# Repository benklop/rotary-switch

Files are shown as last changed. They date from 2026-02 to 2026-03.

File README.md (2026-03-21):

# Rotary Light Switch

3D-printed single-gang US rotary light switch using an EC11 encoder and ESP32-S2 Mini, with a standard faceplate and knob. Control a dimmable/color light from Home Assistant: toggle, dim, hue, and color temperature. Optional RGB LED behind the knob for feedback or night light (controllable as a light in HA).

## Contents

- **openscad/** – Housing (single-gang, 2 3/8" faceplate screws, 3 9/32" box mount). No printed faceplate; use a standard toggle/rotary-dimmer plate.
- **esphome/** – ESPHome config for Lolin S2 Mini: rotary encoder + push button, exposed to Home Assistant.
- **homeassistant/blueprints/automation/** – Speed-sensitive RGB blueprints (`rotary_dimmer_rgb.yaml`, `rotary_dimmer_rgb_with_fan.yaml`): Encoder Speed sensor, Kelvin CT on the light, saturation-first hue mode. With the optional fan button configured, double-press is hue and the fan button toggles fan; without it, double-press toggles fan mode. See [homeassistant/blueprints/automation/README.md](homeassistant/blueprints/automation/README.md).
- **docs/** – Wiring, BOM, assembly.

## Quick start

1. Print the housing (`openscad/`), flash ESPHome (`esphome/`), wire encoder and PSU (see [docs/wiring.md](docs/wiring.md)).
2. Mount encoder, boards, and knob in the housing; install in the wall with a standard faceplate.
3. In Home Assistant, add the device, create the helpers for your blueprint (mode input_select, hue sub-mode select for RGB blueprints, optional fan button entity, 30 s timer — see [homeassistant/blueprints/automation/README.md](homeassistant/blueprints/automation/README.md)), then create an automation from `rotary_dimmer_rgb.yaml` or `rotary_dimmer_rgb_with_fan.yaml`.

See [docs/assembly.md](docs/assembly.md) and [docs/bom.md](docs/bom.md) for full steps and parts.

## Hardware

- EC11 rotary encoder (15 mm shaft, **splined** 6 mm)
- ESP32-S2 Mini (Lolin S2 Mini), [pinout](https://done.land/components/microcontroller/families/esp/esp32/developmentboards/esp32-s2/s2mini/)
- WX-DC12003 5 V 700 mA PSU (23.5×18.1 mm)
- Lutron knob (5.5 mm split-shaft type; heat and form to fit 6 mm splined encoder—see docs); standard single-gang faceplate

## License

Use and modify as you like; no warranty.

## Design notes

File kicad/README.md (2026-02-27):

## KiCad: Rotary switch UI PCB

This folder contains a small PCB intended to mount:

- An **EC11/EC11E-style rotary encoder with push switch**
- A **5 mm through-hole common-cathode RGB LED**
- **3× current-limit resistors** for the LED
- A **1×8 2.54 mm header** for wiring to the ESP32-S2 Mini

### Project files

- `rotary_switch_ui.kicad_pro`
- `rotary_switch_ui.kicad_sch`
- `rotary_switch_ui.kicad_pcb`

### Mechanical reference

The PCB footprint placement is aligned to the OpenSCAD model:

- **Encoder center** at `(0, 0)` mm
- **LED center** at `(0, -9.5)` mm (from `openscad/dimensions.scad` `led_offset_y`)

### Recommended footprints (to assign in schematic)

If you open the schematic and run **Update PCB from Schematic**, assign these footprints first so KiCad can match by reference designator:

- `SW1` (encoder): `Rotary_Encoder:RotaryEncoder_Alps_EC11E-Switch_Vertical_H20mm`
- `D1` (LED): `LED_THT:LED_D5.0mm-4_RGB`
- `R1`, `R2`, `R3` (resistors): `Resistor_SMD:R_0805_2012Metric` (or switch to THT if preferred)
- `J1` (to ESP32): `Connector_PinHeader_2.54mm:PinHeader_1x08_P2.54mm_Vertical`

### Header pinout (J1)

1. `+3V3` (optional; typically not needed for a bare EC11)
2. `GND`
3. `ENC_A` (encoder A → ESP32 GPIO34 per `docs/wiring.md`)
4. `ENC_B` (encoder B → ESP32 GPIO36)
5. `ENC_BTN` (push button → ESP32 GPIO37)
6. `LED_R_IN` (→ R1 → LED_R; ESP32 GPIO4)
7. `LED_G_IN` (→ R2 → LED_G; ESP32 GPIO5)
8. `LED_B_IN` (→ R3 → LED_B; ESP32 GPIO6)

# Rotary front panel PCB

Small PCB to mount the EC11 encoder, 5 mm RGB LED, and current-limiting resistors for the [rotary light switch](../README.md) project. Connects to the ESP32-S2 Mini via a 8-pin header.

## Contents

- **rotary-front.kicad_pro** – KiCad 8 project
- **rotary-front.kicad_pcb** – Board with footprints placed (encoder, LED, 3× 0805 resistors, 1×8 pin header). No schematic yet; create one and then **Update PCB from Schematic**.

## Schematic (create in Eeschema)

Create a new schematic in this project and add:

| Ref | Symbol / part | Footprint | Value / notes |
|-----|---|---|---|
| U1 | **Device:RotaryEncoder_Switch** | **Rotary_Encoder:RotaryEncoder_Alps_EC11E-Switch_Vertical_H20mm** | EC11 with switch |
| D1 | **LED:LED_RGB_CommonCathode** or 4-pin connector | **LED_THT:LED_D5.0mm-4_RGB** | 5 mm common-cathode RGB |
| R1 | **Device:R** | **Resistor_SMD:R_0805_2012Metric** | **470 Ω** (red channel) |
| R2 | **Device:R** | **Resistor_SMD:R_0805_2012Metric** | **430 Ω** (green) |
| R3 | **Device:R** | **Resistor_SMD:R_0805_2012Metric** | **430 Ω** (blue) |
| J1 | **Connector:Conn_01x08** | **Connector_PinHeader_2.54mm:PinHeader_1x08_P2.54mm_Vertical** | To ESP32 |

### Net list (wire to J1)

Use these net names so the PCB matches [../docs/wiring.md](../docs/wiring.md):

| J1 pin | Net name | ESP32-S2 Mini |
|---|---|---|
| 1 | +3V3 (opt) | 3V3 |
| 2 | GND | GND |
| 3 | ENC_A | GPIO 34 |
| 4 | ENC_B | GPIO 36 |
| 5 | ENC_BTN | GPIO 37 |
| 6 | LED_R_IN | GPIO 4 (via R1 470 Ω) |
| 7 | LED_G_IN | GPIO 5 (via R2 430 Ω) |
| 8 | LED_B_IN | GPIO 6 (via R3 430 Ω) |

- Connect **encoder** pins to ENC_A, ENC_B, ENC_BTN, and GND (check your EC11 datasheet for pin order; Alps EC11E footprint uses A, B, C, S1, S2 — map A/B/S1/S2 to ENC_A/ENC_B/ENC_BTN and GND as appropriate; no VCC is required for the encoder itself).
- Connect **LED** common cathode to **GND**; connect R, G, B anodes to the **R**, **G**, **B** nets (i.e. through R1, R2, R3 to the same-named J1 pins). Verify 5 mm RGB pinout (common cathode vs anode, R/G/B order) from your LED datasheet.

Then: **Tools → Assign footprint symbols**, assign the footprints above, **File → Update PCB from Schematic**, and in PCB Editor route the nets (or use the existing placement).

## PCB layout

- **Board size:** 50 mm × 35 mm (Edge.Cuts).
- **Encoder** at top center (shaft position aligned with front-panel 6 mm hole when the board is mounted).
- **LED** below the encoder (matches `led_offset_y = -9.5 mm` in the OpenSCAD dimensions).
- **J1** at bottom for cable to ESP32.

If your front panel or enclosure differs, move footprints in PCB Editor and adjust Edge.Cuts as needed.

## BOM (per board)

| Ref | Part | Value / spec |
|-----|---|---|
| U1 | Alps EC11 or compatible rotary encoder with switch, vertical, 6 mm shaft | 15 mm shaft, splined |
| D1 | 5 mm RGB LED, common cathode | 4-pin |
| R1 | Resistor 0805 | **470 Ω** |
| R2 | Resistor 0805 | **430 Ω** |
| R3 | Resistor 0805 | **430 Ω** |
| J1 | Pin header 1×8, 2.54 mm | Straight, THT |

## Manufacturing

- Single-sided (or two-layer) 1.6 mm FR4; 0.2 mm min trace/space is fine.
- After assembly, mount the PCB behind the 3D-printed front face with the encoder shaft through the 7 mm hole and the LED in the LED cavity; then follow the main [assembly](../docs/assembly.md) for wiring to the ESP32 and PSU.

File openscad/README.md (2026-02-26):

# Rotary Light Switch – OpenSCAD (front panel + back box)

Two **separate printable components** that attach with 4× M3×10 countersunk screws into M3×6 heat-set inserts in the back box.

## Components

### 1. Front panel (`front_lid.scad`)

Flat plate with hole positions for US single-gang: **narrower and shorter**, ~1/4" beyond the outlet box mounting holes.

- **Faceplate screws** (2 3/8" c/c): 2.6 mm holes so 6-32 screws tap into plastic.
- **Outlet box mounting** (3 9/32" c/c): clearance holes.
- **Encoder**: 6 mm shaft hole; **RGB LED**: 4 mm light opening below.
- **4× M3 countersunk** holes for attaching the back box (M3×10 CS from front into inserts).

### 2. Back box (`back_box.scad`)

Box behind the front panel: **height = distance between faceplate mounting holes** (2 3/8" = 60.325 mm) so it fits in the available space in the light switch box. Minimal depth for encoder rear and boards.

- **4× M3×6 heat-set inserts** at the same positions as the front panel M3 holes (press in from inside).
- **Center divider** separating microcontroller (right / +x) from power supply and 120 V wiring (left / −x).
- **2× wire holes** on the back (PSU side) for 16 AWG live and neutral to the PSU module.

## Dimensions (see `dimensions.scad`)

- Panel: `front_width` (~44 mm), `front_height` (~96 mm), `margin_beyond_box_holes` (1/4").
- Back box: `back_box_height` = faceplate screw spacing (60.325 mm), `back_box_internal_depth` (26 mm), `divider_thickness` (2 mm), `wire_hole_dia` (4 mm).
- M3: `m3_clearance_dia`, `m3_cs_head_dia`, `m3_insert_od`, `m3_insert_depth`, `mount_offset_x` / `mount_offset_y`.

## Usage

1. Open `front_lid.scad` or `back_box.scad` in OpenSCAD (each includes `dimensions.scad`).
2. Adjust values in `dimensions.scad` if needed.
3. Render (F6) and export STL for each component.

## Print settings

- **Front panel**: print with front face down (holes up); no supports. Faceplate holes for 6-32 tap; M3 holes are countersunk.
- **Back box**: orient so the mating face (with the four bosses) is down or so the back wall is down; add supports if the divider or bosses need them. After printing, install M3×6 heat-set inserts in the four boss holes (heat and press in).

## Assembly

1. Install heat-set inserts in the back box (4× M3×6 in the boss holes).
2. Mount encoder (and LED) on the front panel; route wires into the back box.
3. Place ESP32 on the MCU side of the divider, PSU on the PSU side; pass 16 AWG through the two back holes to the PSU.
4. Mate the back box to the front panel and secure with 4× M3×10 countersunk screws from the front.
5. Mount to the outlet box and attach the standard faceplate. See `docs/assembly.md` for full build.

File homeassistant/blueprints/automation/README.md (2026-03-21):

# Rotary Encoder Dimmer Blueprints

Use these blueprints with the ESPHome **rotary-lightswitch** firmware in this repo. Rotation speed comes from the on-device **Encoder Speed** sensor (det/s).

**No Home Assistant helpers are required.** Flash the firmware, import the blueprint, then pick the **light** (and **fan** for the fan blueprint) plus the **rotary ESPHome device**. Mode (`normal` / `hue` / `color_temp` / `fan`), hue sub-mode (`saturation` / `hue`), and the idle timeout are handled on the ESP32 (`select` + `script` + **Mode Idle Arm** / **Mode Idle Cancel** buttons). Idle duration is the `idle_timeout` substitution in [esphome/rotary-lightswitch.yaml](../../esphome/rotary-lightswitch.yaml).

On-device entity suffixes (for debugging): `_encoder_speed`, `_button_single` / `_button_double` / `_button_long`, `_knob_led`, `_rotary_mode`, `_hue_adjust`, `_mode_idle_arm`, `_mode_idle_cancel`.

---

## Blueprint: `rotary_dimmer_rgb.yaml` (speed-sensitive light + hue + color temp)

**Hue mode** starts in **saturation**; **single-press** in hue mode toggles saturation ↔ hue (does not toggle the room light).

**Colour temperature** uses `light.turn_on` **`color_temp_kelvin`** on the main light. The **knob LED** is RGB-only (warm/cool proxy in CT mode).

**Long press**: Firmware fires **Button Long** ~500 ms into the hold so CT mode starts while you are still pressing.

### Setup

1. Flash [esphome/rotary-lightswitch.yaml](../../esphome/rotary-lightswitch.yaml).
2. Import `rotary_dimmer_rgb.yaml`, create the automation: **Light**, **rotary device**, optional “use Knob LED”, optional tuning numbers (defaults are fine).
3. If upgrading from an older blueprint, **re-create** the automation so inputs match.

### Behavior

- **Single / double / long press** and **rotate**: as in the in-blueprint description (normal / hue / CT; double-press hue in/out).

---

## Blueprint: `rotary_dimmer_rgb_with_fan.yaml` (light + fan + hue + CT)

Same RGB / Kelvin / hue behaviour as the RGB-only blueprint, plus **fan** mode on the device’s mode select.

**Double-press vs fan**: Optional **fan button** binary sensor — if set, double-press is for hue and the fan button toggles fan mode; if omitted, double-press toggles fan mode.

### Setup

1. Same firmware as above (mode select includes `fan`).
2. Import `rotary_dimmer_rgb_with_fan.yaml`: **Light**, **fan**, **rotary device**, optional **fan button**, optional knob LED and tuning inputs.
3. Remove any legacy `homeassistant/packages/rotary_dimmer_light.yaml` merge if you still had helpers defined there.

### Behavior

- As described in the blueprint (fan LED colours, CT, hue, etc.).

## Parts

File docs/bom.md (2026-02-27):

# Bill of materials (BOM)

| Item | Spec / link | Qty |
|---|---|-----|
| EC11 rotary encoder with switch | 15 mm shaft, **splined** 6 mm (not D-shaft). Various suppliers (e.g. search “EC11 splined shaft”) | 1 |
| ESP32-S2 Mini | Lolin / Wemos S2 Mini, [e.g. Amazon B0B9ZZYFZ4](https://www.amazon.com/gp/product/B0B9ZZYFZ4). Pinout: [DONE.LAND S2 Mini](https://done.land/components/microcontroller/families/esp/esp32/developmentboards/esp32-s2/s2mini/) | 1 |
| 5 V 700 mA power supply | WX-DC12003, 23.5×18.1 mm, contacts on long side. [Datasheet](https://www.jouyaelec.ir/stfiles/getappdocument/1/true/ac92859d-dfbc-4501-aee5-b14eae599f2f.pdf). [Example Amazon B0B2RBP1Z2](https://www.amazon.com/gp/product/B0B2RBP1Z2) | 1 |
| Lutron knob | Designed for 5.5 mm split shaft; see assembly for fitment (heat and form with encoder shaft) | 1 |
| Standard single-gang faceplate | Toggle / rotary-dimmer style (not printed) | 1 |
| Wire | 22–26 AWG for low voltage between encoder, ESP32, and PSU | ~0.5 m |
| Mounting screws | For outlet box (through 3 9/32" holes) and for faceplate (into 2 3/8" holes); #6-32 or M3 typical | 4 |
| 5 mm RGB LED (common cathode) | Tri-color for feedback / night light behind knob | 1 |
| Resistors | 470 Ω (R), 430 Ω × 2 (G, B), 1/4 W current-limiting | 3 |
| Optional | Heat-set inserts for faceplate screw holes; double-sided tape or small screws for boards in slots | — |

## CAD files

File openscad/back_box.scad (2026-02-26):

// Rotary Light Switch - back box (separate component)
// Attaches to front panel with 4× M3×10 countersunk screws into M3×6 heat-set inserts.
// Divider separates MCU (top) from PSU + 120V (bottom). Two wire holes on back in bottom for live/neutral.

include <dimensions.scad>

// --- Helpers ---
boss_radius = (m3_insert_od + 4) / 2;
r = round_radius;  // fillet radius for rounded edges/corners
rib_width = 2.5;   // rib thickness (perpendicular to wall)
rib_boss_overlap = 0.5;  // rib extends into boss by this much for a solid union

module m3_insert_boss() {
  // Boss recessed by m3_boss_rear_cylinder_height so back box front face is flush for lip; stepped hole for screw + insert
  z_front = back_box_total_depth - m3_boss_rear_cylinder_height;  // front face of boss (recessed)
  boss_h = back_box_total_depth - m3_boss_rear_cylinder_height;
  insert_h = m3_insert_depth * 1.5;
  difference() {
    cylinder(d = m3_insert_od + 4, h = boss_h, $fn = 32);
    // Screw clearance through first 2 mm from boss front face
    translate([0, 0, z_front - 1.5])
      cylinder(d1 = m3_insert_od + 0.1, d2 = m3_insert_od + 1, h = 1.5, $fn = 24);
    // Insert cavity starting 2 mm behind boss front face
    translate([0, 0, z_front - insert_h])
      cylinder(d = m3_insert_od + 0.1, h = insert_h, $fn = 24);
  }
}

// Rib from boss to wall; height matches recessed boss so rib doesn't extend past front face
rib_height = back_box_total_depth - m3_boss_rear_cylinder_height;

module boss_rib_x(boss_x, boss_y, toward_positive) {
  inner_x = toward_positive ? (front_width/2 - wall_thickness) : (-front_width/2 + wall_thickness);
  span = abs(inner_x - boss_x) - boss_radius;          // free gap from boss surface to wall
  len = span + rib_boss_overlap;                       // extend rib into boss by overlap
  if (len > 0) {
    x_start = toward_positive
      ? boss_x + boss_radius - rib_boss_overlap        // from inside boss toward +x wall
      : inner_x;                                       // from wall toward inside boss
    translate([x_start, boss_y - rib_width/2, 0])
      cube([len, rib_width, rib_height]);
  }
}

module boss_rib_y(boss_x, boss_y, toward_positive) {
  inner_y = toward_positive ? (back_box_height/2 - wall_thickness) : (-back_box_height/2 + wall_thickness);
  span = abs(inner_y - boss_y) - boss_radius;          // free gap from boss surface to wall
  len = span + rib_boss_overlap;                       // extend rib into boss by overlap
  if (len > 0) {
    y_start = toward_positive
      ? boss_y + boss_radius - rib_boss_overlap        // from inside boss toward +y wall
      : inner_y;                                       // from wall toward inside boss
    translate([boss_x - rib_width/2, y_start, 0])
      cube([rib_width, len, rib_height]);
  }
}

// --- Back box body: perimeter walls + back wall (height = faceplate spacing only) ---
module back_box_shell() {
  inner_w = front_width - 2 * wall_thickness;
  inner_h = back_box_height - 2 * wall_thickness;
  difference() {
    // Outer box: no taller than faceplate screw spacing so it fits in the switch box
    translate([-front_width/2, -back_box_height/2, 0])
      cube([front_width, back_box_height, back_box_internal_depth + wall_thickness]);
    // Interior cavity
    translate([-inner_w/2, -inner_h/2, wall_thickness])
      cube([inner_w, inner_h, back_box_internal_depth + 1]);
  }
}

// Corner chunk to subtract: sharp corner (cube) minus quarter-cylinder. Leaves convex fillet.
// Chunk extends in +x and +y from origin (the corner point).
module vertical_corner_chunk() {
  difference() {
    cube([r + 0.02, r + 0.02, back_box_total_depth + 2]);
    intersection() {
      cylinder(r = r, h = back_box_total_depth + 2, $fn = 32);
      cube([r + 0.02, r + 0.02, back_box_total_depth + 2]);
    }
  }
}

// Edge chunk to subtract along back edge (axis X): bar minus quarter-cylinder. Leaves convex fillet.
// Bar extends in +y and +z from origin (the edge line at y=0, z=0).
module back_edge_chunk_x(len) {
  difference() {
    cube([len, r + 0.02, r + 0.02]);
    translate([0, r, r]) rotate([0, 90, 0]) intersection() {
      cylinder(r = r, h = len, center = true, $fn = 32);
      cube([len, r + 0.02, r + 0.02]);
    }
  }
}
// Edge chunk for edge along Y (bar in x,z).
module back_edge_chunk_y(len) {
  difference() {
    cube([r + 0.02, len, r + 0.02]);
    translate([r, 0, r]) rotate([90, 0, 0]) intersection() {
      cylinder(r = r, h = len, center = true, $fn = 32);
      cube([r + 0.02, len, r + 0.02]);
    }
  }
}

module corner_rounds() {
  fw = front_width;
  bh = back_box_height;
  rr = r + 0.02;  // chunk size so we offset by this to place chunk inside the box
  // 4 vertical corners: subtract corner chunk (cube minus quarter-cylinder) so convex fillet remains.
  // Chunk must extend inward from each corner so we actually cut the box; origin at corner would cut only empty space.
  translate([ fw/2 - rr,  bh/2 - rr, -1]) vertical_corner_chunk();                    // top-right
  translate([-fw/2 + rr,  bh/2 - rr, -1]) mirror([1, 0, 0]) vertical_corner_chunk(); // top-left
  translate([ fw/2 - rr, -bh/2 + rr, -1]) mirror([0, 1, 0]) vertical_corner_chunk(); // bottom-right
  translate([-fw/2 + rr, -bh/2 + rr, -1]) mirror([1, 1, 0]) vertical_corner_chunk();  // bottom-left
}

// --- Horizontal divider (MCU top vs PSU bottom); bottom compartment 20 mm to divider ---
module divider() {
  h = back_box_internal_depth + wall_thickness;
  inner_w = front_width - 2 * wall_thickness;
  divider_y_bottom = -back_box_height/2 + wall_thickness + divider_bottom_compartment_height;
  difference() {
    translate([-inner_w/2, divider_y_bottom, 0])
      cube([inner_w, divider_thickness, h]);
    // Front-center cutout for encoder body (EC11) in case it extends into divider region
    translate([ inner_w / 2 - wall_thickness - wire_slot_offset, divider_y_bottom - 0.5, back_box_total_depth - wire_slot_height - 0.5])
      cube([wire_slot_width , divider_thickness + 1, wire_slot_height + 1]);
  }
}

// --- Faceplate screw boss: cylinder behind each faceplate mounting hole ---
// Cylinder ~10 mm deep with mounting_screw_hole_dia through-hole; back tapers in to meet front wall
module faceplate_screw_boss() {
  z_front = back_box_total_depth;  // inner face of front wall
  z_back  = z_front - faceplate_screw_boss_depth;
  z_center = (z_front + z_back) / 2;
  h = faceplate_screw_boss_depth;
  difference() {
    // Tapered cylinder: full OD at front, tapers to hole diameter at back (meets wall)
    union() {
      translate([0, 0, z_center - h])
        cylinder(
          d1 = mounting_screw_hole_dia, d2 = faceplate_screw_boss_od,
          h = h, center = true, $fn = 32
        );
      translate([0, 0, z_center])
        cylinder(
          d1 = faceplate_screw_boss_od, d2 = faceplate_screw_boss_od,
          h = h, center = true, $fn = 32
        );
    }
    union() {
      // Through-hole for screw
      translate([0, 0, z_center])
        faceplate_screw_clearance_hole();
      // remove the external part of the boss
      translate([-faceplate_screw_boss_od/2,-faceplate_screw_boss_od/2, z_back / 2])
        cube([faceplate_screw_boss_od, faceplate_screw_boss_od/2, z_back * 2]);
    }
  }
}

module faceplate_screw_clearance_hole() {
  cylinder(d = mounting_screw_hole_dia, h = faceplate_screw_boss_depth * 2, center = true, $fn = 24);
}

module clearance_holes() {
    translate([0,  faceplate_hole_offset_y, back_box_total_depth]) faceplate_screw_clearance_hole();
    translate([0, -faceplate_hole_offset_y, back_box_total_depth]) faceplate_screw_clearance_hole();
}

// --- Wire pass-through holes on back (PSU side only) ---
module wire_holes() {
  z_back_center = wall_thickness / 2;
  translate([wire_hole_x1, wire_hole_y, z_back_center]) cylinder(d = wire_hole_dia, h = wall_thickness + 2, center = true, $fn = 24);
  translate([wire_hole_x2, wire_hole_y, z_back_center]) cylinder(d = wire_hole_dia, h = wall_thickness + 2, center = true, $fn = 24);
}
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

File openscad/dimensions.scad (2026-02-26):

// Rotary Light Switch - US single-gang housing dimensions
// All units in mm unless noted

// ----- US device mount (single-gang) -----
// Faceplate screws go INTO the print; standard faceplate attaches here
faceplate_screw_spacing = 60.325;  // 2 3/8" center-to-center, vertical
// Outlet box mounting: screws go THROUGH the print into the box
electrical_box_screw_spacing = 83.344; // 3 9/32" center-to-center, vertical

// Minimal margin beyond the outermost (box) mounting holes; ~1/4" typical
margin_beyond_box_holes = 6.35;    // 1/4"

electrical_box_depth = 63.5;   // ~2.5" typical; for reference
wall_thickness = 2.0;
tolerance = 0.3;            // slot clearance for boards

// Front panel only: narrower and shorter, ~1/4" beyond box holes
// Height = box screw spacing + margin above and below
front_height = electrical_box_screw_spacing + 2 * margin_beyond_box_holes;  // ~96 mm
// Width = narrow; enough for knob and screw holes (no full faceplate width)
front_width = 44.45;       // ~1.75"; adjust to taste
front_center_x = front_width / 2;
front_center_y = front_height / 2;

// Screw hole positions (from front face center; y positive = up)
faceplate_hole_offset_y = faceplate_screw_spacing / 2;  // ±30.16 mm from center
electrical_box_hole_offset_y = electrical_box_screw_spacing / 2; // ±41.67 mm from center
// Inner (faceplate) holes: slightly small so 6-32 screws tap into plastic and hold
faceplate_screw_hole_dia = 3.6;   // pilot for 6-32 thread-cutting in plastic (~0.10")
// Outer (box) holes: clearance for screws that pass through into the box
mounting_screw_hole_dia = 4.0;             // #6-32 or M3  + 0.4 for clearance
// Back box: cylinder behind each faceplate mounting hole (screw pilot from front)
faceplate_screw_boss_depth = 10;           // cylinder depth into box (~10 mm)
faceplate_screw_boss_od = 8;               // outer diameter at front; tapers to hole at back
// Tabs for electrical box mounting holes (max 1/2" each dimension)
mounting_tab_width = 12.7;          // 1/2" max width of tab with box-mount hole
mounting_tab_length = 12.7;         // 1/2" length of tab (corner cutout depth)

// ----- EC11 rotary encoder -----
ec11_body_dia = 11;
ec11_shaft_dia = 6;        // Splined shaft 6 mm
ec11_mount_hole_dia = 7.0; // Encoder mounting hole 7 mm 
ec11_mount_pitch = 5;
ec11_shaft_length = 15;
ec11_nut_flat = 8;         // M6 nut flat-to-flat approx
ec11_nut_thickness = 2.5;
encoder_slot_depth = 8;    // cavity behind front for encoder body

// ----- RGB LED (behind knob: feedback / night light) -----
led_dia = 5;               // 5 mm round tri-color LED
led_depth = 7;             // cavity depth for LED body + leads
led_hole_dia = 5;          // opening in front for light (slightly under LED dome)
led_offset_y = -9.5;         // LED center below shaft (y); visible under knob

// ----- ESP32-S2 Mini (Lolin S2 Mini) -----
esp32_width = 34.4;
esp32_height = 25.4;
esp32_slot_clearance = tolerance;

// ----- WX-DC12003 power supply -----
psu_length = 23.5;         // long side (contacts on this side)
psu_width = 18.1;
psu_slot_clearance = tolerance;
psu_height = 12;           // typical PCB height; adjust from datasheet if needed

// ----- Front panel ↔ back box attachment (M3) -----
// 4× M3×10 countersunk screws from front panel into M3×6 heat-set inserts in back box
m3_clearance_dia = 3.5;           // through-hole for M3 screw
m3_cs_head_dia = 8.0;            // countersunk head diameter (M3 flat/countersunk)
m3_cs_angle = 90;                // countersink angle (degrees)
m3_insert_od = 4.5;              // heat-set insert outer diameter (M3×6 typical)
m3_insert_depth = 6;              // insert length
m3_boss_height = 2 + m3_insert_depth;  // min height at front for insert; back_box uses full depth
// Four mounting positions (x, y) from center; must lie inside back_box_height
mount_offset_x = 15;             // ± from center
mount_offset_y = 22;             // ± from center (inside back_box_height/2)

// Slot to pass power wiring through
wire_slot_width = 1.5;
wire_slot_height = 10;
wire_slot_offset = 2;

// ----- Back box -----
// Height = distance between faceplate mounting holes so it fits in the switch box
back_box_height = faceplate_screw_spacing;  // 2 3/8" = 60.325 mm max
// Depth: minimal for encoder rear + components
back_box_internal_depth = 35;    // internal depth from mating face to back wall
back_box_total_depth = back_box_internal_depth + wall_thickness;  // full depth (walls)
round_radius = 1.5;              // back and corner round/fillet (replaces chamfer)
m3_boss_rear_cylinder_height = 2.0;  // raised cylinder behind M3 CS hole for strength
m3_boss_cylinder_od = 10;        // outer diameter of raised cylinder behind M3 hole
divider_thickness = 2.0;         // center divider (separates MCU top from PSU bottom)
divider_bottom_compartment_height = 18;  // mm from inner bottom to divider; PSU + wire holes in bottom
// Wire pass-through on back (PSU side, bottom) for 16 AWG live/neutral (side by side)
wire_hole_dia = 4;             // 16 AWG with insulation fits through
wire_hole_y = -23;               // vertical position (in bottom compartment)
wire_hole_x1 = -8.5;               // left hole (x)
wire_hole_x2 = -3.5;               // right hole, a few mm from x1
psu_side_bottom = true;          // PSU + AC wires in bottom compartment

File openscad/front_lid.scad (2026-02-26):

// Rotary Light Switch - front panel only (printable)
// Mounts to electrical box with 3 9/32" holes; faceplate attaches with 2 3/8" screws.
// Panel is narrower and shorter: ~1/4" beyond the box mounting holes.

include <dimensions.scad>

// Corner radius for front panel (1/8")
corner_radius = 25.4 / 8;  // 3.175 mm
// Smoothness of rounded corners (affects exported STL, not just preview)
// Smaller $fs = smoother arcs; ~0.3 mm is good for print quality
fillet_fragment_size = 0.3;

// --- Helpers ---
module screw_hole(d = mounting_screw_hole_dia, h = 20) {
  cylinder(d = d, h = h, center = true, $fn = 24);
}

module encoder_shaft_hole() {
  // Round hole for 6 mm splined shaft; shaft passes through to knob
  cylinder(d = ec11_mount_hole_dia + 0.2, h = wall_thickness + 2, center = true, $fn = 32);
}

module led_light_hole() {
  // Opening in front so LED glow is visible behind knob
  translate([0, led_offset_y, 0])
    cylinder(d = led_hole_dia + 0.2, h = wall_thickness + 2, center = true, $fn = 24);
}

// M3 countersunk through-hole for back box attachment (screw from front at z=0, head flush)
module m3_cs_through_hole() {
  // Through-hole from front (z=0) through plate and raised cylinder (to z=wall_thickness+cylinder_height)
  translate([0, 0, (wall_thickness + m3_boss_rear_cylinder_height) / 2])
    cylinder(d = m3_clearance_dia, h = wall_thickness + m3_boss_rear_cylinder_height + 2, center = true, $fn = 24);
  // Countersink (90°) at front face (z=0) so head sits flush
  translate([0, 0, wall_thickness / 2])
    cylinder(r1 = (m3_cs_head_dia + 0.4 ) / 2, r2 = m3_clearance_dia / 2, h = wall_thickness + 0.5, center = true, $fn = 24);
}

// Raised cylinder on back face (box side), which prints facing up; extends in +z from z=wall_thickness
module m3_boss_rear_cylinder() {
  translate([0, 0, wall_thickness + m3_boss_rear_cylinder_height / 2])
    cylinder(d = m3_boss_cylinder_od, h = m3_boss_rear_cylinder_height, center = true, $fn = 32);
}

// 2D corner cutout shape (rectangle) for outline
module corner_cutout_2d() {
  cutout_x = (front_width - mounting_tab_width) / 2;
  cutout_y = mounting_tab_length;
  square([cutout_x + 0.01, cutout_y + 0.01]);
}

// 3D corner cutout for difference (kept for any 3D use)
module corner_cutout() {
  cutout_x = (front_width - mounting_tab_width) / 2;
  cutout_y = mounting_tab_length;
  cube([cutout_x + 0.01, cutout_y + 0.01, wall_thickness + 2], center = false);
}

// --- Front panel (flat plate with holes, lip recess, raised M3 bosses) ---
module front_plate() {
  cutout_x = (front_width - mounting_tab_width) / 2;
  difference() {
    union() {
      // Panel: build tabbed outline first, then round all remaining corners
      linear_extrude(wall_thickness) {
        $fs = fillet_fragment_size;
        offset(r = -corner_radius) offset(delta = corner_radius)   // fillet concave (tab meets body)
        offset(r = corner_radius) offset(delta = -corner_radius)  // round convex (tab ends, outer)
        difference() {
          square([front_width, front_height], center = true);
          union() {
            translate([-front_width/2,  front_height/2 - mounting_tab_length]) corner_cutout_2d(); // top-left
            translate([ front_width/2 - cutout_x,  front_height/2 - mounting_tab_length]) corner_cutout_2d(); // top-right
            translate([-front_width/2, -front_height/2]) corner_cutout_2d(); // bottom-left
            translate([ front_width/2 - cutout_x, -front_height/2]) corner_cutout_2d(); // bottom-right
          }
        }
      }
      // Raised cylinders on back face (box side, prints up) for strength and to keep countersink within thickness
      translate([ mount_offset_x,  mount_offset_y, 0]) m3_boss_rear_cylinder();
      translate([ mount_offset_x, -mount_offset_y, 0]) m3_boss_rear_cylinder();
      translate([-mount_offset_x,  mount_offset_y, 0]) m3_boss_rear_cylinder();
      translate([-mount_offset_x, -mount_offset_y, 0]) m3_boss_rear_cylinder();
    }

    // Encoder shaft hole (center)
    translate([0, 0, 0])
      encoder_shaft_hole();
    // RGB LED light opening (behind knob)
    led_light_hole();
    // Faceplate screw holes (6-32 bite into plastic; use smaller pilot)
    translate([0, faceplate_hole_offset_y, 0]) screw_hole(d = faceplate_screw_hole_dia, h = wall_thickness + 2);
    translate([0, -faceplate_hole_offset_y, 0]) screw_hole(d = faceplate_screw_hole_dia, h = wall_thickness + 2);
    // Outlet box mounting holes (screws go THROUGH into box; clearance)
    translate([0, electrical_box_hole_offset_y, 0]) screw_hole(h = wall_thickness + 2);
    translate([0, -electrical_box_hole_offset_y, 0]) screw_hole(h = wall_thickness + 2);
    // 4× M3 countersunk holes for back box (M3×10 CS into heat-set inserts)
    translate([ mount_offset_x,  mount_offset_y, 0]) m3_cs_through_hole();
    translate([ mount_offset_x, -mount_offset_y, 0]) m3_cs_through_hole();
    translate([-mount_offset_x,  mount_offset_y, 0]) m3_cs_through_hole();
    translate([-mount_offset_x, -mount_offset_y, 0]) m3_cs_through_hole();
  }
}

front_plate();

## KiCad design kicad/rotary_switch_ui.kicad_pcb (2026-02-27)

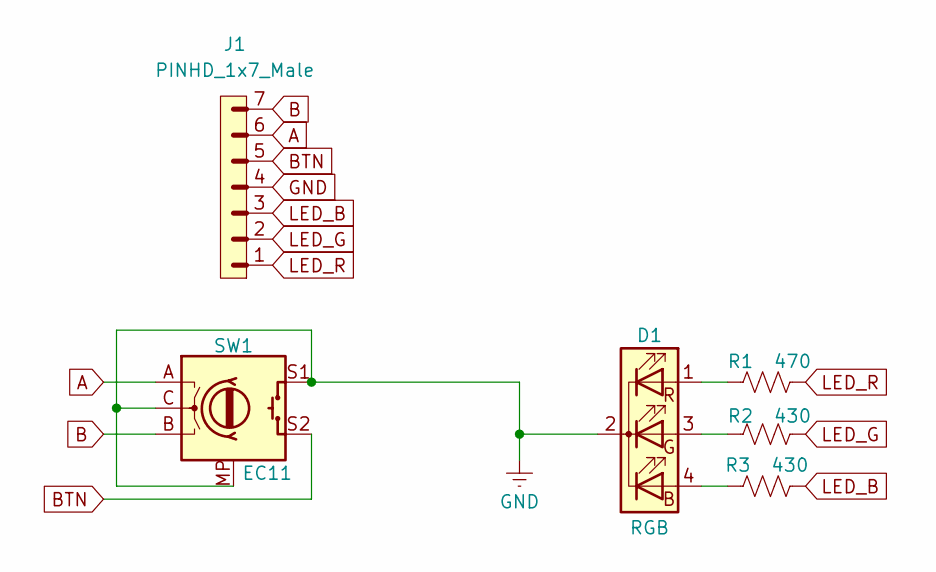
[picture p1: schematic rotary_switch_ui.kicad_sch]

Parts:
D1: RGB; LED_D5.0mm-4_RGB
J1: PINHD_1x7_Male; PinHeader_1x07_P2.54mm_Vertical
R1: 470; R_Axial_DIN0207_L6.3mm_D2.5mm_P7.62mm_Horizontal
R2, R3: 430; R_Axial_DIN0207_L6.3mm_D2.5mm_P7.62mm_Horizontal
SW1: EC11; RotaryEncoder_Alps_EC11E-Switch_Vertical_H20mm

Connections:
A: J1.6, SW1.A
B: J1.7, SW1.B
BTN: J1.5, SW1.S2
GND: D1.2 (K), J1.4, SW1.C, SW1.MP, SW1.S1
LED_B: J1.3, R3.2
LED_G: J1.2, R2.2
LED_R: J1.1, R1.2
unnamed: D1.4 (BA), R3.1
unnamed: D1.3 (GA), R2.1
unnamed: D1.1 (RA), R1.1

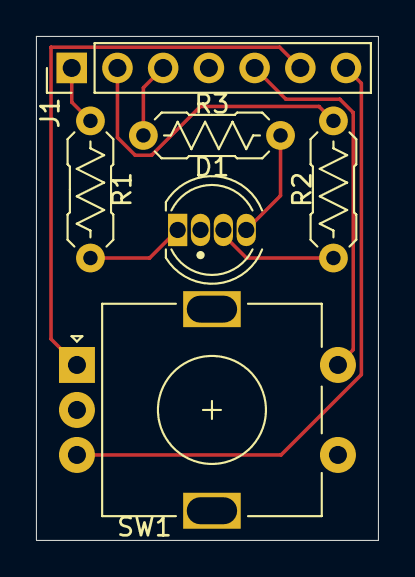
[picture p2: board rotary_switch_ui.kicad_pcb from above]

Board: 2 copper layers, 19.0 x 28.0 mm, 6 parts (0 on the bottom side), 10 nets.

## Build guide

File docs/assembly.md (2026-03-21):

# Assembly

1. **Print the housing**  
   Use `openscad/housing.scad`; export STL and print. See [openscad/README.md](../openscad/README.md) for dimensions and print notes.

2. **Flash ESPHome**  
   - Copy `esphome/secrets.yaml.example` to `secrets.yaml` and set WiFi and (optionally) API/OTA keys.  
   - Run `esphome run esphome/rotary-lightswitch.yaml` and flash the ESP32-S2 Mini (hold GPIO0, press RST to enter flash mode).

3. **Encoder and LED**  
   - Attach the encoder to the front face with the shaft on the side with the countersinks. Tighten the nut until secure. Use the washer that came with the encoder on the outside to protect the plastic while tightening the nut.  
   - Press-fit the LED into the front face so the lens faces the same way as the encoder shaft.  
   - Connect the ground pins of the LED and the encoder to each other.  
   - Solder a resistor to each of the R, G, and B legs of the LED, using the correct resistor for each (R: 470 Ω, G and B: 430 Ω each).  
   - Attach wires to each of the remaining signal legs on the encoder (ENC_A, ENC_B, ENC_BTN), the shared ground, and the R/G/B resistors.  
   - Wire these to the ESP32-S2: ENC_A → GPIO34, ENC_B → GPIO36, ENC_BTN → GPIO37, GND → GND; R → GPIO4, G → GPIO5, B → GPIO6 (each via its resistor); LED cathode → GND. See [wiring.md](wiring.md).

4. **PSU**  
   - Solder 18 gauge wires to the live and neutral holes on the PSU. Use **white for neutral** and **black for live**.  
   - Strip and tin the other end of these wires so they don’t fray or break when tightened in wire nuts.  
   - Tie a knot in the live/neutral wires close to the PSU board as strain relief for assembly.  
   - Solder a **red** wire to the ground connection and a **black** wire to the 5 V connection of the PSU.  
   - Connect the red lead to **GND** and the black lead to **VBUS** on the ESP32-S2 Mini.

5. **Assembly**  
   TBD

6. **Install in the wall**  
   - Power off at the breaker.  
   - Feed the PSU AC input to the appropriate mains (via a qualified installation if required).  
   - Mount the assembly to the outlet box using the **3 9/32"** mounting holes.  
   - Screw the **standard faceplate** to the housing using the **2 3/8"** screw positions.

7. **Home Assistant**  
   - Add the ESPHome device to Home Assistant.  
   - Create helpers per [homeassistant/blueprints/automation/README.md](../homeassistant/blueprints/automation/README.md): for `rotary_dimmer_rgb.yaml`, an input_select (`normal`, `hue`, `color_temp`), a hue sub-mode input_select (`saturation`, `hue`), and a timer (e.g. 30 s).  
   - Import `rotary_dimmer_rgb.yaml` (or `rotary_dimmer_rgb_with_fan.yaml` if you control a fan) and create an automation: light, **Encoder Speed** sensor, button binary sensors, helpers, and optional knob LED.

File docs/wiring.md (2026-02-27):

# Wiring

## ESP32-S2 Mini (Lolin S2 Mini) ↔ Encoder

| Encoder net | Function | ESP32-S2 Mini GPIO |
|---|---|---|
| ENC_A | Encoder A | GPIO 34 |
| ENC_B | Encoder B | GPIO 36 |
| ENC_BTN | Push button | GPIO 37 |
| GND | Ground | GND |

- Enable the ESP32-S2’s internal pull-ups on ENC_A and ENC_B in firmware (see ESPHome config). No external pull-up resistors are provided on the PCB.
- The EC11 is a passive mechanical gray-code encoder; it does not need a VCC connection.

## RGB LED (behind knob)

| LED (common cathode) | ESP32-S2 Mini |
|---|---|
| Red anode | GPIO 4 (via 470 Ω) |
| Green anode | GPIO 5 (via 430 Ω) |
| Blue anode | GPIO 6 (via 430 Ω) |
| Common cathode | GND |

- Use a 5 mm common-cathode RGB LED. R: 470 Ω between GPIO4 and anode; G and B: 430 Ω each between GPIO5/GPIO6 and anodes.
- The LED appears in Home Assistant as a light entity for feedback or night light (e.g. dim red at night).

## Power

- **WX-DC12003**: AC input on the board edge (contacts on the 23.5 mm side). **5 V / 0.7 A** output.
- Connect PSU 5 V and GND to ESP32 **VBUS** (or 5 V) and **GND** for power. The board regulates to 3.3 V internally.
- Do not run high voltage (mains) inside the 3D-printed housing; keep AC only at the PSU input side and use a proper enclosure or wall box for mains.

## Summary

1. PSU 5 V → ESP32 VBUS (or 5 V pin), PSU GND → ESP32 GND.
2. ENC_A → GPIO34, ENC_B → GPIO36, ENC_BTN → GPIO37, GND → GND.
3. RGB LED: R → GPIO4 via 470 Ω; G → GPIO5, B → GPIO6 (each via 430 Ω); cathode → GND.

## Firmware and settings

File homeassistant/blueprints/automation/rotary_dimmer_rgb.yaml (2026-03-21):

blueprint:
  name: Rotary Encoder Speed-Sensitive RGB Color Light
  description: >
    Controls a dimmable/color light with three modes selectable by the encoder button.
    Brightness step size scales automatically with how fast you spin — measured on the 
    ESP32 itself (1 ms resolution) so speed classification is clean and jitter-free.

    Requires the updated rotary-lightswitch ESPHome firmware which publishes
    an "Encoder Speed" sensor (det/s, signed: + = CW, − = CCW).

    Pick the ESPHome **device** once; encoder, button, Knob LED, **Rotary Mode** / **Hue Adjust**
    selects, and **Mode Idle Arm/Cancel** buttons are resolved from the device (no HA helpers).
    Idle timeout is fixed in ESPHome (`idle_timeout` substitution in the device YAML).

    Behavior:
      - Single press:  toggle light on/off (in normal and CT mode); in hue mode, toggles between
        saturation adjust and hue adjust (does not toggle the light).
      - Rotate (normal mode): dim / brighten (speed-sensitive)
      - Double press:  enter hue mode; rotate adjusts saturation first (visible colour even from white);
        single-press switches to hue-angle adjust and back; double-press again (or timeout) to exit
      - Long press:    enter colour-temperature mode (fires mid-hold once the hold time is reached — flash new firmware);
        rotate to change CT in Kelvin-sized steps; long-press again (or timeout) to exit
      - Knob LED (optional): RGB-only proxy — off in normal when the room light is on or the sun is up;
        soft orange night glow when the main light is off after sunset (normal mode only); HS→RGB in hue mode;
        in CT mode, amber↔blue-white RGB (main light still uses color_temp_kelvin).
      - Idle exit is handled on the device (encoder + HA blueprint arm the same restartable script); rotation resets it.
  domain: automation

  input:
    light_entity:
      name: Light
      description: Dimmable/colour light to control.
      selector:
        entity:
          domain: light

    rotary_device:
      name: Rotary switch (ESPHome device)
      description: >
        The ESPHome device for this knob (e.g. "Living Room Dimmer"). All encoder and
        button entities plus the Knob LED are picked up from this device automatically.
      selector:
        device:

    use_knob_led_feedback:
      name: Use Knob LED on device
      description: >
        When enabled, drives the device's RGB Knob LED (entity id ending in _knob_led)
        for night glow, hue/CT indication, etc. Disable if you removed the LED or want no feedback.
      default: true
      selector:
        boolean:

    # ── Speed thresholds ────────────────────────────────────────────────────
    slow_threshold:
      name: Slow / medium threshold (det/s)
      description: >
        Turns slower than this are "slow". Typical deliberate single-detent
        turn is around 1–3 det/s; a comfortable sweep is 5–10 det/s.
      default: 3.0
      selector:
        number:
          min: 0.5
          max: 10.0
          step: 0.5
          unit_of_measurement: "det/s"

    fast_threshold:
      name: Medium / fast threshold (det/s)
      description: Turns faster than this are "fast".
      default: 8.0
      selector:
        number:
          min: 2.0
          max: 25.0
          step: 0.5
          unit_of_measurement: "det/s"

    # ── Brightness step sizes ─────────────────────────────────────────────────
    brightness_step_slow:
      name: Brightness slow step (% per detent)
      description: Brightness change per detent for a slow, deliberate turn.
      default: 3
      selector:
        number:
          min: 1
          max: 15
          step: 1
          unit_of_measurement: "%"

    brightness_step_medium:
      name: Brightness medium step (% per detent)
      description: Brightness change per detent at a comfortable sweep speed.
      default: 10
      selector:
        number:
          min: 1
          max: 30
          step: 1
          unit_of_measurement: "%"

    brightness_step_fast:
      name: Brightness fast step (% per detent)
      description: Brightness change per detent when spinning quickly.
      default: 25
      selector:
        number:
          min: 5
          max: 50
          step: 1
          unit_of_measurement: "%"

    # ── Hue step sizes ──────────────────────────────────────────────────────
    hue_step_slow:
      name: Hue slow step (degrees per detent)
      description: Hue change per detent for a slow turn.
      default: 5
      selector:
        number:
          min: 1
          max: 30
          step: 1
          unit_of_measurement: "°"

    hue_step_medium:
      name: Hue medium step (degrees per detent)
      description: Hue change per detent at a comfortable sweep speed.
      default: 10
      selector:
        number:
          min: 1
          max: 30
          step: 1
          unit_of_measurement: "°"
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

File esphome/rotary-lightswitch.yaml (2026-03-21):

# Rotary Light Switch - ESPHome configuration for ESP32-S2 Mini (Lolin S2 Mini)
# EC11 rotary encoder (ENC_A, ENC_B, ENC_BTN) + RGB LED behind knob
# Board: lolin_s2_mini. Upload: hold GPIO0, press RST to enter flash mode.
# Wiring: ENC_A=GPIO34, ENC_B=GPIO36, ENC_BTN=GPIO37; RGB R=GPIO4, G=GPIO5, B=GPIO6
#         (470 Ω on R, 430 Ω on G and B, between each GPIO and LED anode)
#         Encoder common → GND; LED cathode → GND; PSU 5 V → VBUS

substitutions:
  name: rotary-lightswitch
  friendly_name: Rotary Light Switch
  # Idle timeout for hue / colour-temp / fan modes (matches blueprint default).
  idle_timeout: 30s

esphome:
  name: "${name}"
  friendly_name: "${friendly_name}"

esp32:
  board: esp32-s2-saola-1
  framework:
    type: esp-idf

api:
  encryption:
    key: !secret api_encryption_key

ota:
  - platform: esphome
    password: !secret ota_password

wifi:
  ssid: !secret wifi_ssid
  password: !secret wifi_password
  ap:
    ssid: "${friendly_name} Fallback"
    password: !secret ap_password

captive_portal:

logger:

# ── Mode state on-device (Home Assistant blueprints use select.* / button.* below;
#    object_id suffixes: _rotary_mode, _hue_adjust, _mode_idle_arm, _mode_idle_cancel) ─
select:
  - platform: template
    name: "Rotary Mode"
    id: rotary_mode
    optimistic: true
    restore_value: true
    initial_option: normal
    options:
      - normal
      - hue
      - color_temp
      - fan
    set_action:
      - if:
          condition:
            lambda: return x == "normal";
          then:
            - script.stop: mode_idle_arm
          else:
            - script.execute: mode_idle_arm

  - platform: template
    name: "Hue Adjust"
    id: hue_adjust
    optimistic: true
    restore_value: true
    initial_option: saturation
    options:
      - saturation
      - hue
    set_action:
      - if:
          condition:
            lambda: return id(rotary_mode).current_option() == "hue";
          then:
            - script.execute: mode_idle_arm

# ── Long press: fire Button Long ~500 ms after press while still held ─────────
# (on_multi_click only completes patterns on release, so HA/LED would lag.)
script:
  # After ${idle_timeout} without restart, return to normal + saturation (replaces HA timer).
  - id: mode_idle_arm
    mode: restart
    then:
      - delay: ${idle_timeout}
      # publish_state avoids template select set_action (would restart idle while still in hue).
      - lambda: |-
          id(rotary_mode).publish_state("normal");
          id(hue_adjust).publish_state("saturation");

  - id: maybe_restart_mode_idle
    then:
      - if:
          condition:
            lambda: |-
              auto m = id(rotary_mode).current_option();
              return m == "hue" || m == "color_temp" || m == "fan";
          then:
            - script.execute: mode_idle_arm

  - id: encoder_long_press_arm
    mode: restart
    then:
      - delay: 500ms
      - if:
          condition:
            binary_sensor.is_on: encoder_button
          then:
            - binary_sensor.template.publish:
                id: encoder_button_long
                state: true
            - delay: 200ms
            - binary_sensor.template.publish:
                id: encoder_button_long
                state: false

# ── Global: tracks millis() of the last encoder detent ──────────────────────
# Used to compute inter-detent interval → speed in detents/s.
# Not persisted across reboots (intentional: stale timestamp would give a
# false "very slow" reading on the first turn after a reboot, which is fine).
globals:
  - id: last_enc_ms
    type: uint32_t
    restore_value: no
    initial_value: '0'

# ── RGB LED behind knob ──────────────────────────────────────────────────────
# R: 470 Ω, G/B: 430 Ω each (current-limiting on GPIO side).
output:
  - platform: ledc
    pin: GPIO4
    id: led_red
    channel: 0
  - platform: ledc
    pin: GPIO5
    id: led_green
    channel: 1
  - platform: ledc
    pin: GPIO6
    id: led_blue
    channel: 2

light:
  - platform: rgb
    name: "Knob LED"
    id: knob_led
    red: led_red
    green: led_green
    blue: led_blue
    restore_mode: ALWAYS_OFF
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

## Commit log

2026-02-26 Add initial project files for Rotary Light Switch
    - Created .gitignore to exclude build artifacts and sensitive files.
    - Added README.md with project overview, contents, quick start guide, and hardware specifications.
    - Included assembly instructions in docs/assembly.md.
    - Provided a bill of materials in docs/bom.md.
    - Documented wiring details in docs/wiring.md.
    - Added ESPHome configuration in esphome/rotary-lightswitch.yaml.
    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
    [back_box.scad, dimensions.scad, front_lid.scad]
2026-02-27 Refactor assembly and wiring documentation for Rotary Light Switch
    Add a PCB for mounting the LED and the encoder
    [rotary_switch_ui.kicad_pcb, rotary_switch_ui.kicad_sch]
2026-02-27 Enhance Rotary Light Switch functionality and automation
    - Added encoder speed sensor to ESPHome configuration for improved responsiveness.
    - Implemented speed-based adjustments for brightness, hue, and color temperature in Home Assistant blueprints.
    - Introduced thresholds and multipliers for fine-tuning speed sensitivity in automation scripts.
2026-02-27 Update Rotary Dimmer Light automation and configuration
    - Modified entity descriptions in the automation blueprint for clarity.
    - Changed entity domain from `text_sensor` to `sensor` for encoder direction and button action entities.
    - Corrected value templates in automation actions to properly reference input entities.
    - Added a new package file for rotary dimmer light configuration, including input select and timer for mode management.
    - Implemented automation logic for rotary encoder actions, including mode switching and light control based on button presses.
2026-02-27 Refine Rotary Dimmer Light automation logic and entity definitions
    - Updated entity descriptions for clarity and consistency.
    - Corrected value templates in automation actions to properly reference input entities, ensuring accurate functionality for mode switching and light control.
    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
2026-02-27 Refactor Rotary Dimmer Light automation for improved variable handling and logic consistency
    - Introduced new variable definitions for light, fan, and mode selection to streamline automation logic.
    - Updated value templates to reference defined variables instead of input entities, enhancing readability and maintainability.
    - Ensured consistent handling of brightness, hue, and color temperature adjustments based on encoder speed and thresholds.
2026-02-27 Refactor Rotary Lightswitch configuration and automation for CW/CCW functionality
    - Updated ESPHome configuration to simplify encoder handling by replacing delta degrees with binary sensors for clockwise and counterclockwise actions.
    - Adjusted resolution for encoder steps to improve responsiveness.
    - Modified Home Assistant automation blueprint to utilize new binary sensors, enhancing clarity and functionality for light dimming based on encoder rotation.
    - Improved variable definitions and descriptions for better maintainability and understanding.
2026-02-27 Fix timing configuration in Rotary Lightswitch YAML to correct ON duration from 0. qqqqqqq5s to 0.5s, ensuring proper functionality of the binary sensor automation.
    [rotary-lightswitch.yaml]
2026-03-21 Add rotary dimmer RGB with fan automation blueprint and update helper package
    - Introduced a new automation blueprint for controlling a dimmable light and fan using a rotary encoder, allowing for speed-sensitive adjustments in brightness, fan speed, and color temperature.
    - Updated the helper package to support the new blueprint, removing the previous rotary dimmer light automation and simplifying the configuration for user-friendly setup.
2026-03-21 Refactor rotary dimmer automation blueprints for speed-sensitive RGB control
    - Updated rotary dimmer automation blueprint to enhance functionality for RGB color lights, including speed-sensitive brightness adjustments based on encoder rotation speed.
    - Added new parameters for slow, medium, and fast thresholds for brightness, hue, and color temperature adjustments.
    - Improved user experience with detailed behavior descriptions and optional feedback LED configurations.
    - Introduced a separate blueprint for rotary dimmer with fan control, allowing independent fan speed adjustments and mode toggling.
    - Enhanced documentation and descriptions for clarity on usage and configuration.
2026-03-21 Add rotary dimmer RGB blueprint with enhanced hue control and saturation adjustments
    - Introduced a new blueprint for rotary dimmer RGB control, allowing for speed-sensitive adjustments in brightness, hue, and color temperature.
    - Added input select helpers for hue sub-mode and saturation step sizes, improving user customization options.
    - Updated behavior descriptions to clarify functionality in different modes, including detailed interactions for single and double presses.
    - Enhanced documentation for setup and usage, ensuring a better user experience.
2026-03-21 Add long press functionality to rotary lightswitch for immediate color temperature mode activation
    - Implemented a new script to handle long press actions on the rotary encoder button, allowing for immediate entry into color temperature mode after a 500 ms hold.
    - Updated the binary sensor configuration to trigger the long press script on button press and stop it on release, enhancing responsiveness.
    - Revised documentation to reflect changes in long press behavior and its impact on automation interactions.
2026-03-21 correct if condition indentation
    [rotary-lightswitch.yaml]
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2026-03-21 Refactor rotary dimmer blueprints for improved entity resolution and documentation
    - Updated rotary dimmer RGB blueprints to automatically resolve encoder, button, and knob LED entities from the selected ESPHome device, simplifying user setup.
    - Revised README and documentation to clarify the new entity resolution process and the importance of re-creating automations after blueprint upgrades.
    - Enhanced input parameters for rotary devices, including options for knob LED feedback, ensuring better integration and usability.
    - Streamlined automation actions to utilize the new entity resolution, improving overall functionality and user experience.
    [rotary_dimmer_rgb.yaml, rotary_dimmer_rgb_with_fan.yaml]
2026-03-21 Fix rotary lightswitch condition checks to use current_option for mode evaluation
    - Updated condition checks in the rotary lightswitch configuration to utilize `current_option()` instead of `state` for determining the current mode.
    - Ensured consistency in mode evaluation logic across scripts, enhancing reliability in mode transitions and actions.
    [rotary-lightswitch.yaml]
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
